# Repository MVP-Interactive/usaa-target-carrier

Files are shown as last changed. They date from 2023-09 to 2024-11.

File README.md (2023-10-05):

# 9dof sensor/light package with PoE

## About
Connect an ESP32-POE-ISO to a lsm9ds1 sensor via StemmaQT and a WS2811
light strand along with 12V power.

Because of the 12V power for the LEDs, the PoE on the ESP32-POE will not be used.

## Connections

Attach the Adafruit LSM9D1 Stemma power to the small 4 pin connector.

Connect the USB cable to the Olimex ESP32 board.

Connect the 10 pin ribbon cable to the Olimex ESP32 board.

Connect the LEDs to the 3 pin LED connector.

Connect the PoE extractor's ethernet out to the Olimex ESP32 board.

Connect the PoE extractor's 12v barrel to the 12v barrel on the board.

If using debug/programming USB-C board, not that while you can
physically plug the USB-C in other direction, only one direction will
work due to a flay in the board.

## Software

To build the software, use Arduino IDE 2.2.x.

Add the following board manager URLs in Preferences:
https://adafruit.github.io/arduino-board-index/package_adafruit_index.json
https://espressif.github.io/arduino-esp32/package_esp32_index.json

After that then press Ctrl+Shift+B to bring up the board manager dialog.
In the search box, type "esp32" and look for "esp32 by Expressif Systems" and click Install.

Add the following libraries in the Library Manager:
Arduino_LSM9DS1
Ethernet
Adafruit 9DOF
Adafruit BusIO
Adafruit NeoPixel
Adafruit Unified Sensor
ArduinoJson
CRC
CircularBuffer
HttpClient

If during the process, additional libraries are recommended, accept them.

## BOM
https://www.adafruit.com/product/4634
https://www.adafruit.com/product/4210
https://www.olimex.com/Products/IoT/ESP32/ESP32-POE-ISO/open-source-hardware

https://www.amazon.com/gp/product/B01AG923EU/

https://www.amazon.com/gp/product/B07L7QDZJW/

https://www.amazon.com/dp/B01DC0KIT2

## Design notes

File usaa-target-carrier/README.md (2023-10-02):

## LED strand pinout

1 - 12v   - RED
2 - DINv5 - WHITE
3 - GND   - BLUE

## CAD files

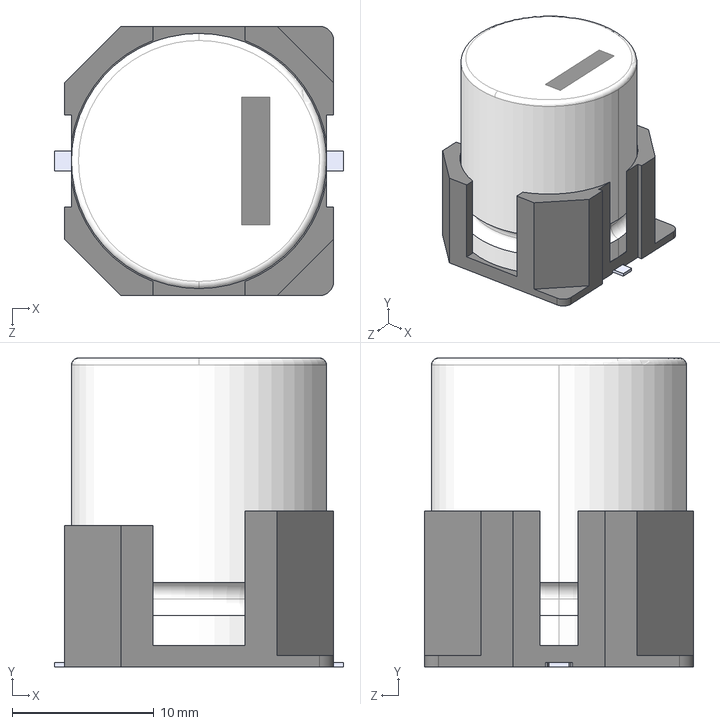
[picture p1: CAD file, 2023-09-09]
usaa-target-carrier/SnapEDA/EEETP1J102V.step
20.4 x 21.8 x 19.0 mm

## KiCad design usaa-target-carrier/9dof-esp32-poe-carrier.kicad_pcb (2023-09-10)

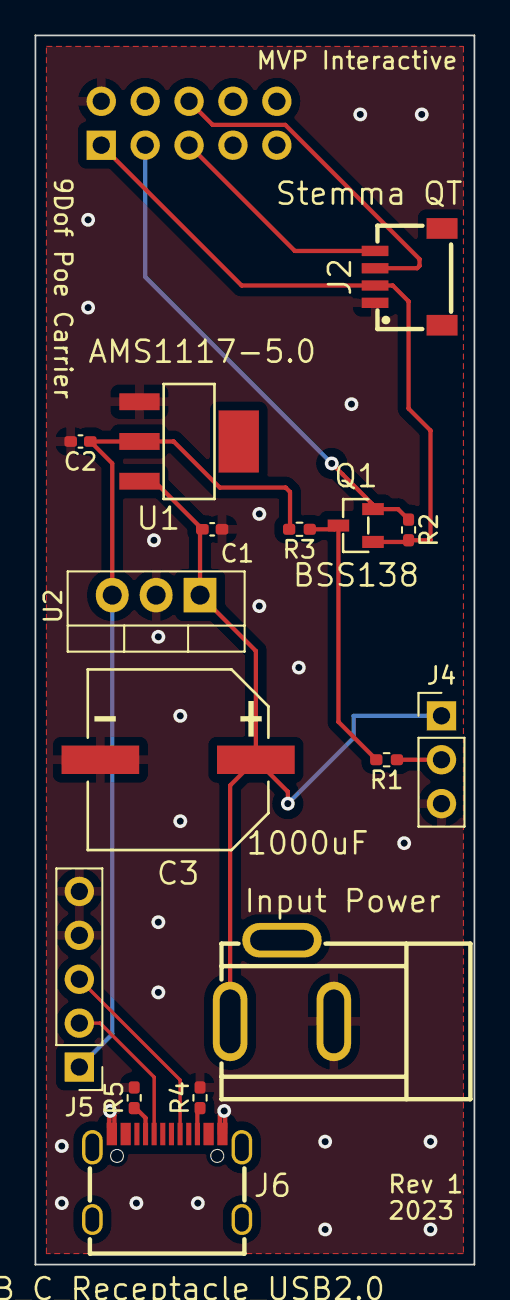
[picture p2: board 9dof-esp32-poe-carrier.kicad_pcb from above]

Board: 2 copper layers, 25.4 x 71.1 mm, 17 parts (1 on the bottom side), 13 nets.

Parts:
C1, C2: 10uF; C_0402_1005Metric_Pad0.74x0.62mm_HandSolder
C3: 1000uF; CAP-SMD_BD10.0-L10.3-W10.3-FD
J1: Input Power; DC-IN-TH_DC005-T
J2: Stemma QT; CONN-SMD_4P-P1.00_SM04B-SRSS-TB-LF-SN
J3: UEXT_Slave; UEXT_SLAVE_BACKSIDE
J4: WS2811_strand; PinHeader_1x03_P2.54mm_Vertical
J5: USB to ESP32; PinHeader_1x05_P2.54mm_Vertical
J6: USB_C_Receptacle_USB2.0; USB-C_SMD-TYPE-C-31-M-12
Q1: BSS138; SOT-23-3_L2.9-W1.3-P1.90-LS2.4-BR
R1: 470; R_0402_1005Metric_Pad0.72x0.64mm_HandSolder
R2, R3: 10K; R_0402_1005Metric_Pad0.72x0.64mm_HandSolder
R4, R5: 5.1k; R_0402_1005Metric_Pad0.72x0.64mm_HandSolder
U1: AMS1117-5.0; SOT-223-3_L6.7-W3.7-P2.30-LS7.0-BR
U2: STM L7805CV; TO-220-3_Vertical

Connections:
+3V3: J2.2 (V+), J3.1 (3V3), Q1.1 (G), R2.2
+5V: C2.1, J5.1 (VBUS), R3.2, U1.2 (VO), U2.3 (VO)
+12V: C1.1, C3.1, J1.1 (In), J4.1, U1.3 (VI), U2.1 (VI)
D+: J5.3 (D+), J6.A6 (D+), J6.B6 (D+)
D-: J5.2 (D-), J6.A7 (D-), J6.B7 (D-)
DINv5: Q1.3 (D), R1.2, R3.1
DO3v3: J3.3 (TXD), Q1.2 (S), R2.1
GND: C1.2, C2.2, C3.2, J1.2 (Ext), J2.1 (GND), J3.2 (GND), J4.3, J5.4 (GND), J5.5 (Shield), J6.A1 (GND), J6.A12 (GND), J6.B1 (GND), J6.B12 (GND), R4.2, R5.2, U1.1 (GND), U2.2 (GND)
unnamed: J4.2, R1.1
unnamed: J6.A5 (CC1), R5.1
unnamed: J6.B5 (CC2), R4.1
SCL: J2.4 (SCL), J3.5 (SCL)
SDA: J2.3 (SDA), J3.6 (SDA)

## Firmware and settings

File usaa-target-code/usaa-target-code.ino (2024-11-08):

// -*- mode: C++;  tab-width: 2; c-basic-offset: 2;  -*-

#include <Wire.h>
#include <SPI.h>
#include <Arduino.h>

#include <WiFi.h>
#include <WiFiMulti.h>
#include <Client.h>
#include <ETH.h>

#include "esp_system.h"

#include <Adafruit_LSM9DS1.h>
#include <Adafruit_Sensor.h>    // not used in this demo but required!
#include <Adafruit_NeoPixel.h>  //  Library that provides NeoPixel functions

#include <HTTPClient.h>
#include <ArduinoJson.h>
#include <CRC.h>

#include "sensor_calibration.h"
#include "usaa_api.h"
#include "leds.h"

const String TAG = "rev_8";
const float MIN_CONFIG_MAG = 0.01;  // smallest value we want to accept for a threshold
const float MIN_DEBUG_MAG = 0.25;   // smallest value we want to debug

#define WDT_TIMEOUT_S 120  // define a 2 minute WDT (Watch Dog Timer)

// 99 is invalid.  1 is normal power on. 6 is task watchdog. For others
// see: https://github.com/espressif/esp-idf/blob/272b4091f1f1ff169c84a4ee6b67ded4a005a8a7/components/esp_system/include/esp_system.h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
int BootReason = 99;

enum HTTPMsg {
  HTTP_HIT,
  HTTP_STATUS,
  HTTP_CFG
};
// Default threshold to something close to what is normally used
float hit_thresh = 1.0;
// We don't want to do the sqrt part of the magnitudes, so we square the value to
// compare against.
float hit_thresh_sq = hit_thresh * hit_thresh;

long long lastHit = 0;
uint32_t hit_wait = 1000;   // How long to enforce no hits after a hit, in ms
uint32_t hit_flash = 1000;  // How long to strobe LEDs in ms
uint8_t white_level = 100;
uint16_t blink_interval = 200;

// Which pin on the Arduino is connected to the NeoPixels?
// On a Trinket or Gemma we suggest changing this to 1:
const uint8_t LED_PIN = 4;

// How many NeoPixels are attached to the Arduino?
const uint8_t LED_COUNT = 50;
const uint8_t LED_SPLIT = 18;


uint8_t sensor_id;
IPAddress ip(192, 168, 0, 21);
const IPAddress gw(192, 168, 0, 1);
const IPAddress subnet(255, 255, 255, 0);

Adafruit_NeoPixel strip(LED_COUNT, LED_PIN, NEO_GRB + NEO_KHZ800);

// i2c
Adafruit_LSM9DS1 lsm = Adafruit_LSM9DS1();

long long lastStatus = 0;  // ms
long long lastConfig = 0;
sensors_vec_t zeroedAccel;
bool calibrationNeeded = false;

const uint32_t statusInterval = 60000;  // ms
const uint32_t configInterval = 60000;

const String RESET_REASONS[] = {
  "ESP_RST_UNKNOWN",    //!< Reset reason can not be determined
  "ESP_RST_POWERON",    //!< Reset due to power-on event
  "ESP_RST_EXT",        //!< Reset by external pin (not applicable for ESP32)
  "ESP_RST_SW",         //!< Software reset via esp_restart
  "ESP_RST_PANIC",      //!< Software reset due to exception/panic
  "ESP_RST_INT_WDT",    //!< Reset (software or hardware) due to interrupt watchdog
  "ESP_RST_TASK_WDT",   //!< Reset due to task watchdog
  "ESP_RST_WDT",        //!< Reset due to other watchdogs
  "ESP_RST_DEEPSLEEP",  //!< Reset after exiting deep sleep mode
  "ESP_RST_BROWNOUT",   //!< Brownout reset (software or hardware)
  "ESP_RST_SDIO",       //!< Reset over SDIO
  "ESP_RST_USB",        //!< Reset by USB peripheral
  "ESP_RST_JTAG",       //!< Reset by JTAG
};

void setupSensor() {
  // 1.) Set the accelerometer range
  lsm.setupAccel(lsm.LSM9DS1_ACCELRANGE_4G);
  //lsm.setupAccel(lsm.LSM9DS1_ACCELRANGE_4G);
  //lsm.setupAccel(lsm.LSM9DS1_ACCELRANGE_8G);
  //lsm.setupAccel(lsm.LSM9DS1_ACCELRANGE_16G);

  // 2.) Set the magnetometer sensitivity
  //lsm.setupMag(lsm.LSM9DS1_MAGGAIN_4GAUSS);

  // 3.) Setup the gyroscope
  //lsm.setupGyro(lsm.LSM9DS1_GYROSCALE_245DPS);
}

static bool eth_connected = false;

void WiFiEvent(WiFiEvent_t event) {
  switch (event) {
    case ARDUINO_EVENT_ETH_START:
      Serial.println("ETH Started");
      //set eth hostname here
      ETH.setHostname("esp32-ethernet");
      break;
    case ARDUINO_EVENT_ETH_CONNECTED:
      Serial.println("ETH Connected");
      break;
    case ARDUINO_EVENT_ETH_GOT_IP:
      Serial.print("ETH MAC: ");
      Serial.print(ETH.macAddress());
      Serial.print(", IPv4: ");
      Serial.print(ETH.localIP());
      if (ETH.fullDuplex()) {
        Serial.print(", FULL_DUPLEX");
      }
      Serial.print(", ");
      Serial.print(ETH.linkSpeed());
      Serial.println("Mbps");
      eth_connected = true;
      break;
    case ARDUINO_EVENT_ETH_DISCONNECTED:
      Serial.println("ETH Disconnected");
      eth_connected = false;
      break;
    case ARDUINO_EVENT_ETH_STOP:
      Serial.println("ETH Stopped");
      eth_connected = false;
      break;
    default:
      break;
  }
}

void setupNetwork() {
  WiFi.onEvent(WiFiEvent);

  ETH.begin();
  Serial.print("ETH MAC: ");
  Serial.println(ETH.macAddress());

  uint64_t chipid = ESP.getEfuseMac();  // The chip ID is essentially its MAC address(length: 6 bytes).

  uint8_t* mac = (uint8_t*)&chipid;
  sensor_id = (calcCRC8(mac, 8) & 0x7f) + 20;
  ip = IPAddress(192, 168, 0, sensor_id);
  APIUpdateUrls(sensor_id);

  ETH.config(ip, gw, subnet, gw, gw);
}

void checkStatusConfig() {
  unsigned long now = millis();

  if (lastStatus == 0 || now > lastStatus + statusInterval) {
    APIPostStatus(sensor_id, TAG);
    lastStatus = now;
  }

  if (lastConfig == 0 || now > lastConfig + configInterval) {
    APIConfig config = APIGetConfig();
    if (config.threshold_is_set && config.threshold >= MIN_CONFIG_MAG) {
      hit_thresh = config.threshold;
      hit_thresh_sq = hit_thresh * hit_thresh;
      Serial.println("New hit_thresh: " + String(hit_thresh));
    }

    if (config.hit_wait_is_set) {
      hit_wait = config.hit_wait;
      Serial.println("New hit_wait: " + String(hit_wait));
    }

    if (config.hit_flash_is_set) {
      hit_flash = config.hit_flash;
      Serial.println("New hit_flash: " + String(hit_flash));
    }

    if (config.blink_interval_is_set) {
      blink_interval = config.blink_interval;
      Serial.println("New hit_flash: " + String(blink_interval));
    }

    if (config.white_level_is_set) {
      white_level = config.white_level;
      Serial.println("New white_level: " + String(white_level));
    }

    lastConfig = now;
  }
}


void setup() {
  Serial.begin(115200);

  while (!Serial) {
    delay(1);  // will pause Zero, Leonardo, etc until serial console opens
  }

  Serial.println("\n Starting...\n");
  Serial.println("\n Rev " + TAG + " ...\n");
  Serial.flush();

  strip.begin();  // INITIALIZE NeoPixel strip object (REQUIRED)
  strip.show();   // Turn OFF all pixels ASAP
  //strip.setBrightness(100); // Set BRIGHTNESS to about 1/5 (max = 255)

  Serial.println("MVP Hit Sensor ...");
  delay(1);

  Wire.begin(13, 16);  // init I2C on the respective pins

  // Try to initialise and warn if we couldn't detect the chip
  if (!lsm.begin()) {
    Serial.println("Oops ... unable to initialize the LSM9DS1. Check your wiring!");
    Serial.flush();
    while (1)
      ;
  }
  //Serial.println("Found LSM9DS1 9DOF");

  // helper to just set the default scaling we want, see above!
  setupSensor();
  setupNetwork();

  checkStatusConfig();

  writeLEDs(REGULAR, true);

  calibrateSensor(&lsm, &zeroedAccel);
}

void writeLEDs(LedState state, bool goSlow) {
  switch (state) {
    case OFF:
      strip.clear();
      break;
    case HIT:
      {
        long long now = millis();
        int32_t diff = now - lastHit;
        int blinkState = (diff / blink_interval) & 0x00000001;

        if (blinkState) {
          for (int i = 0; i < strip.numPixels(); i++) {
            if (i < LED_SPLIT) {
              strip.setPixelColor(i, 0, 0, 255);
            } else {
              strip.setPixelColor(i, white_level, white_level, white_level);
            }
          }
        } else {
          for (int i = 0; i < strip.numPixels(); i++) {
            if (i < LED_SPLIT) {
              strip.setPixelColor(i, white_level, white_level, white_level);
            } else {
              strip.setPixelColor(i, 0, 0, 255);
            }
          }
        }
        strip.show();  //  Update strip to match
                       //  Pause for a moment
      }
      break;
    case REGULAR:
      //remember NEO_GRB
      for (int i = 0; i < strip.numPixels(); i++) {  // For each pixel in strip...
        if (i < LED_SPLIT) {
          strip.setPixelColor(i, 0, 0, 255);
        } else {
          strip.setPixelColor(i, white_level, white_level, white_level);  //  Set pixel's color (in RAM)
        }
        if (goSlow) {
          strip.show();
          delay(20);
        }
      }
      strip.show();  //  Update strip to match
                     //  Pause for a moment

      break;
    case DISCONNECTED:
      for (int i = 0; i < strip.numPixels(); i++) {  // For each pixel in strip...
        strip.setPixelColor(i, 0, 255, 0);
      }
      strip.show();  //  Update strip to match
                     //  Pause for a moment
      break;
  }
}

void debugInfo(float magnitude_sq, sensors_vec_t a, sensors_vec_t delta) {
  Serial.print("MagSqr: ");
  Serial.print(magnitude_sq);
  Serial.print(", HitThreshold: ");
  Serial.print(hit_thresh_sq);

  // print accelerometer values
  Serial.printf(", Accel X: %.2f, Y: %.2f, Z: %.2f\n", a.x, a.y, a.z);

  // print deltas
  Serial.printf("Deltas - X: %.2f, Y: %.2f, Z: %.2f\n", delta.x, delta.y, delta.z);
}

void loop() {
  checkStatusConfig();

  sensors_vec_t accel;
  sensors_vec_t delta;
  float magnitude_sq = calculateMagnitude(&lsm, &accel, &delta, &zeroedAccel);

  if (magnitude_sq >= MIN_DEBUG_MAG) {
    debugInfo(magnitude_sq, accel, delta);
  }

  bool isHit = false;
  long long now = millis();

  if (lastHit && now < lastHit + hit_wait) {
    isHit = false;
  } else if (!calibrationNeeded && magnitude_sq >= hit_thresh_sq) {
    isHit = true;
    lastHit = now;
    if (eth_connected) {
      APIPostHit();
      calibrationNeeded = true;
    }
  }

  if (lastHit && now < lastHit + hit_flash) {
    isHit = true;
  }

  if (!eth_connected)
    writeLEDs(DISCONNECTED, false);
  else if (isHit)
    writeLEDs(HIT, false);
  else
    writeLEDs(REGULAR, true);

  if (calibrationNeeded && now > lastHit + hit_wait) {
    calibrateSensor(&lsm, &zeroedAccel);
    calibrationNeeded = false;
  }
}

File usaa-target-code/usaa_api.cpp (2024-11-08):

// -*- mode: C++;  tab-width: 2; c-basic-offset: 2;  -*-

#include <HTTPClient.h>
#include <ArduinoJson.h>

#include "usaa_api.h"

const char* hitUrlBase = "http://192.168.0.2:5300/api/sensor/";
const char* statusUrlBase = "http://192.168.0.2:5300/api/sensor/status/";
const char* configUrlBase = "http://192.168.0.2:5300/api/sensor/config/";

String hitUrl;
String statusUrl;
String configUrl;

void APIUpdateUrls(uint8_t sensor_id) {
  hitUrl = hitUrlBase + String(sensor_id);
  statusUrl = statusUrlBase + String(sensor_id);
  configUrl = configUrlBase + String(sensor_id);
  Serial.println("hitURL: " + hitUrl);
  Serial.println("statusURL: " + statusUrl);
  Serial.println("configURL: " + configUrl);
}

void APIPostHit() {

  HTTPClient http;
  http.begin(hitUrl);

  Serial.print("[HTTP] POST HIT...\n");
  // start connection and send HTTP header
  int httpCode = http.POST(NULL, 0);

  // httpCode will be negative on error
  if (httpCode > 0) {
    // HTTP header has been send and Server response header has been handled
    Serial.printf("[HTTP] POST... code: %d\n", httpCode);

    String payload = http.getString();
    Serial.println("PL: " + payload);
    return;
  }
  Serial.print("[HTTP] POST FAILED.\n");
}

const String RESET_REASONS[] = {
    "ESP_RST_UNKNOWN",    //!< Reset reason can not be determined
    "ESP_RST_POWERON",    //!< Reset due to power-on event
    "ESP_RST_EXT",        //!< Reset by external pin (not applicable for ESP32)
    "ESP_RST_SW",         //!< Software reset via esp_restart
    "ESP_RST_PANIC",      //!< Software reset due to exception/panic
    "ESP_RST_INT_WDT",    //!< Reset (software or hardware) due to interrupt watchdog
    "ESP_RST_TASK_WDT",   //!< Reset due to task watchdog
    "ESP_RST_WDT",        //!< Reset due to other watchdogs
    "ESP_RST_DEEPSLEEP",  //!< Reset after exiting deep sleep mode
    "ESP_RST_BROWNOUT",   //!< Brownout reset (software or hardware)
    "ESP_RST_SDIO",       //!< Reset over SDIO
    "ESP_RST_USB",        //!< Reset by USB peripheral
    "ESP_RST_JTAG",       //!< Reset by JTAG
};

void APIPostStatus(uint8_t sensor_id, const String & rev) {

  DynamicJsonDocument doc(65536);
  doc["uptime"] = (float)(millis() / 1024.0f);
  doc["reboot_cause"] = RESET_REASONS[esp_reset_reason()];
  doc["id"] = sensor_id;
  doc["rev"] = rev;
  String json;
  serializeJson(doc, json);

  HTTPClient http;
  http.begin(statusUrl);
  http.addHeader("accept", "application/json");
  http.addHeader("Content-Type", "application/json");

  Serial.print("[HTTP] POST STATUS...\n");
  // start connection and send HTTP header
  int httpCode = http.POST(json);

  // httpCode will be negative on error
  if (httpCode > 0) {
    // HTTP header has been send and Server response header has been handled
    Serial.printf("[HTTP] POST... code: %d\n", httpCode);

    String payload = http.getString();
    Serial.println("PL: " + payload);
    return;
  }
  Serial.print("[HTTP] POST FAILED.\n");
}

APIConfig APIGetConfig() {
  APIConfig ret_val;
  memset(&ret_val, 0, sizeof(ret_val));

  HTTPClient http;
  http.begin(configUrl);

  Serial.print("[HTTP] GET CONFIG...\n");
  // start connection and send HTTP header
  int httpCode = http.GET();

  // httpCode will be negative on error
  if (httpCode > 0) {
    // HTTP header has been send and Server response header has been handled
    Serial.printf("[HTTP] GET... code: %d\n", httpCode);

    String payload = http.getString();

    DynamicJsonDocument doc(2048);
    deserializeJson(doc, payload);

    bool semi_success = false;  // Set true if one field can be read.
    if (doc.containsKey("id")) {
      uint8_t id = doc["id"].as<uint8_t>();
      Serial.println("Sid: " + String(id));
      semi_success = true;
    }
    if (doc.containsKey("threshold")) {
      float t = doc["threshold"].as<float>();
      Serial.println("threshold: " + String(t));
      ret_val.threshold = t;
      ret_val.threshold_is_set = true;
      semi_success = true;
    } else
      Serial.print("[HTTP] GET DIDN'T HAVE Threshold.\n");

    if (doc.containsKey("hit_wait")) {
      float t = doc["hit_wait"].as<uint32_t>();
      Serial.println("hit_wait: " + String(t));
      ret_val.hit_wait = t;
      ret_val.hit_wait_is_set = true;
      semi_success = true;
    } else
      Serial.print("[HTTP] GET DIDN'T HAVE hit_wait.\n");

    if (doc.containsKey("hit_flash")) {
      float t = doc["hit_flash"].as<uint32_t>();
      Serial.println("hit_flash: " + String(t));
      ret_val.hit_flash = t;
      ret_val.hit_flash_is_set = true;
      semi_success = true;
    } else
      Serial.print("[HTTP] GET DIDN'T HAVE hit_flash.\n");

    if (doc.containsKey("white_level")) {
      float t = doc["white_level"].as<uint8_t>();
      Serial.println("white_level: " + String(t));
      ret_val.white_level = t;
      ret_val.white_level_is_set = true;
      semi_success = true;
    } else
      Serial.print("[HTTP] GET DIDN'T HAVE white_level.\n");

    if (doc.containsKey("blink_interval")) {
      float t = doc["blink_interval"].as<uint32_t>();
      Serial.println("blink_interval: " + String(t));
      ret_val.blink_interval = t;
      ret_val.blink_interval_is_set = true;
      semi_success = true;
    } else
      Serial.print("[HTTP] GET DIDN'T HAVE blink_interval.\n");


    if (!semi_success) {
      Serial.println("PL: " + payload);
      Serial.print("Doc: ");
      serializeJson(doc, Serial);
    }

  } else
    Serial.print("[HTTP] GET FAILED.\n");

  return ret_val;
}

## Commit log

2023-09-02 Import initial components.
    [9dof-esp32-poe-carrier.kicad_pcb, 9dof-esp32-poe-carrier.kicad_sch]
2023-09-09 update with a bunch of parts extracted from EasyEDA. Change 1000uf cap.
    [EEETP1J102V.step]
2023-09-09 Updated redone schematic.
    [9dof-esp32-poe-carrier.kicad_pcb, 9dof-esp32-poe-carrier.kicad_sch]
2023-09-10 Fiddle with parts, add via stiching, add silkscreen labels.
    [9dof-esp32-poe-carrier.kicad_pcb, 9dof-esp32-poe-carrier.kicad_sch]
2023-09-23 Move project to subdir for organization sake.
    [9dof-esp32-poe-carrier.kicad_pcb, 9dof-esp32-poe-carrier.kicad_sch, EEETP1J102V.step]
2023-09-26 Change watchdog timeout to not fail when http fails.
    [usaa-target-code.ino]
2023-09-26 LED fixes. Set IP automatically.
    [usaa-target-code.ino]
2023-09-27 Fix the LED split, flip colors, add disconnected state to LEDs.
    [usaa-target-code.ino]
2023-09-27 Fix URLS.
    Reorder headers. Speed up sample checking.
    [usaa-target-code.ino]
2023-09-27 Start collecting sample history.
2023-09-27 Switch to vector magnatudes for hit detection.
2023-09-27 Add tag, tweak debug sensor threshold, add comments.
2023-09-28 Fix config parseing. Fix config using wrong URL, change hitWait.
    [api.ino, usaa-target-code.ino]
2023-10-02 Add white_level and blink_interval to config. Fix parseing ints in config.
    [usaa-target-code.ino, usaa_api.cpp]
2023-10-05 Update README.md
    Add missing steps for board support in IDE.
2023-10-11 Reset reasons now strings, also bump rev.
    [usaa-target-code.ino, usaa_api.cpp]
2023-10-11 Slow LEDs on startup. Lower defaul white level. Add rev to status. Do a status/config cycle before any LEDs.
2023-10-11 increase LED startup speed.
2024-09-04 Add missing leds.h, update api url
    [usaa-target-code.ino, usaa_api.cpp]
2024-10-30 Calibrate accelerometer vector and compare against its deltas to trigger hits
